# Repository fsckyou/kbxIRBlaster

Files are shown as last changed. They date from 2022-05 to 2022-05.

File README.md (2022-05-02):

# What the fork?
Yep, this project is a fork of the fantastic open hardware designed by Keith Burzinkski. Check out [the awesome design that this fork is based on](https://github.com/kbx81/kbxIRBlaster)! In many ways, this project is inferior to what he made, but intentionally inferior!

# Why the fork?
I used to buy Tuya IR blasters, pop them open and re-flash the firmware with ESPhome Like many IoT folks used to do. Then they stopped including wifi modules compatible with ESPhome. Well, left with no alternative, I guess I'll have to make them myself! A quick search found Keith's project which met most of my goals, but he designed it for high quality, maximum flexibility, and convenience of the user. My goal is primarily low cost, similarity to the old Tuya products, and bonus points if it can be assembled by JLC PCB.

# kbx and fsckyou IR Blaster

## What?

Just another ESP8266-based IR Blaster. It was designed with
 [ESPHome](https://esphome.io) in mind but should work fine with
 [Tasmota](https://tasmota.github.io/docs/) or any other app, really.

This design is round and should be pretty omnidirectional similar to the Tuya products you can buy on Amazon or Aliexpress.

I'll post images once I have them produced. As of now, this is only a design in progress.

## How?

I'll fill this part in later once the design is more final. ;)

 ## Legal stuff and License

The circuit schematics and PCB found here are licensed under the
 [Creative Commons Attribution-ShareAlike 4.0 International License](http://creativecommons.org/licenses/by-sa/4.0/).



_Happy building!_

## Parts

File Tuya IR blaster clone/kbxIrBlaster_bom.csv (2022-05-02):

Component | Quantity Per PCB | References | Value | MPN1 | MPN2 | Footprint | Population
1 | 3 | C6 C7 C8 | 100 nF | CC0805KRX7R7BB104 |  | C_0805_2012Metric
2 | 1 | C1 | 1 uF | C0805C105K4RACTU |  | C_0805_2012Metric
3 | 1 | C5 | 4.7 uF | C2012X5R1H475K125AB |  | C_0805_2012Metric
4 | 4 | C2 C3 C4 C9 | 10 uF | GRM21BC81C106ME15L |  | C_0805_2012Metric
5 | 2 | D1 D2 | 5V | LSM0805543V |  | LED_0805_2012Metric
6 | 8 | D10 D12 D14 D16 D18 D20 D22 D24 | CH1 | LTE-4206 |  | LED_D5.0mm
7 | 8 | D9 D11 D13 D15 D17 D19 D21 D23 | CH1 | APT2012F3C |  | LED_0805_2012Metric
8 | 5 | D5 D6 D7 D8 D29 | CH1 | APT2012EC |  | LED_0805_2012Metric
9 | 3 | D25 D26 D28 | MBR120 | MBR120VLSFT1G |  | D_SOD-123F
10 | 1 | D3 | STATUS | APT2012SECK |  | LED_0805_2012Metric
11 | 1 | D27 | TX | APT2012VBC/D |  | LED_0805_2012Metric
12 | 1 | D4 | USER | APT2012SYCK |  | LED_0805_2012Metric
13 | 1 | D30 | VBUS | APT2012ZGCK |  | LED_0805_2012Metric
14 | 1 | J3 | 5 TO 6 VDC | 163-179PH-EX |  | BarrelJack_Horizontal
15 | 1 | J2 | N/A | 105017-0001 |  | USB_Micro-B_Molex-105017-0001
16 | 5 | Q1 Q2 Q3 Q4 Q7 | 2N7002 | 2N7002-7-F |  | SOT-23
17 | 2 | Q5 Q6 | MMSS8050 | MMSS8050 |  | SOT-23
18 | 4 | R10 R12 R14 R16 | 27 | RC0805FR-0727RL |  | R_0805_2012Metric
19 | 4 | R9 R11 R13 R15 | 51 | RC0805FR-0751RL |  | R_0805_2012Metric
20 | 1 | R3 | 120 | RT0805FRE07120RL |  | R_0805_2012Metric
21 | 7 | R4 R5 R6 R7 R8 R20 R22 | 1K2 | RT0805FRE072K7L |  | R_0805_2012Metric
22 | 1 | R2 | 1K6 | RT0805FRE071K6L |  | R_0805_2012Metric
23 | 1 | R19 | 4K7 | RT0805FRE074K7L |  | R_0805_2012Metric
24 | 1 | R1 | 8K2 | RT0805FRE078K2L |  | R_0805_2012Metric
25 | 6 | R17 R18 R21 R23 R24 R25 | 10K | RC0805FR-0710KL |  | R_0805_2012Metric
26 | 2 | SW1 SW2 | RESET | PTS645VK582LFS |  | SW_Tactile_SPST_Angled_PTS645Vx58-2LFS
27 | 1 | U2 | AP2112K-3.3 | AP2112M-3.3TRG1 |  | SOT-23-5
28 | 1 | U1 | ESP32-WROOM-32D | ESP32-WROOM-32D |  | ESP32-WROOM-32
29 | 1 | U3 | FT232RL | FT232RL |  | SSOP-28_5.3x10.2mm_P0.65mm
30 | 1 | U4 | TSOP382xx | TSOP38238 |  | Vishay_MINICAST-3Pin
31 | 1 | U5 | TSOP382xx | TSOP38256 |  | Vishay_MINICAST-3Pin

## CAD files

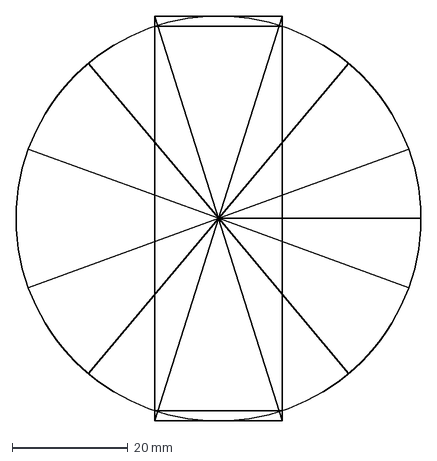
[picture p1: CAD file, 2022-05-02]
Tuya IR blaster clone/kbxIrBlasterDiscPCB.dxf
70.0 x 70.0 mm

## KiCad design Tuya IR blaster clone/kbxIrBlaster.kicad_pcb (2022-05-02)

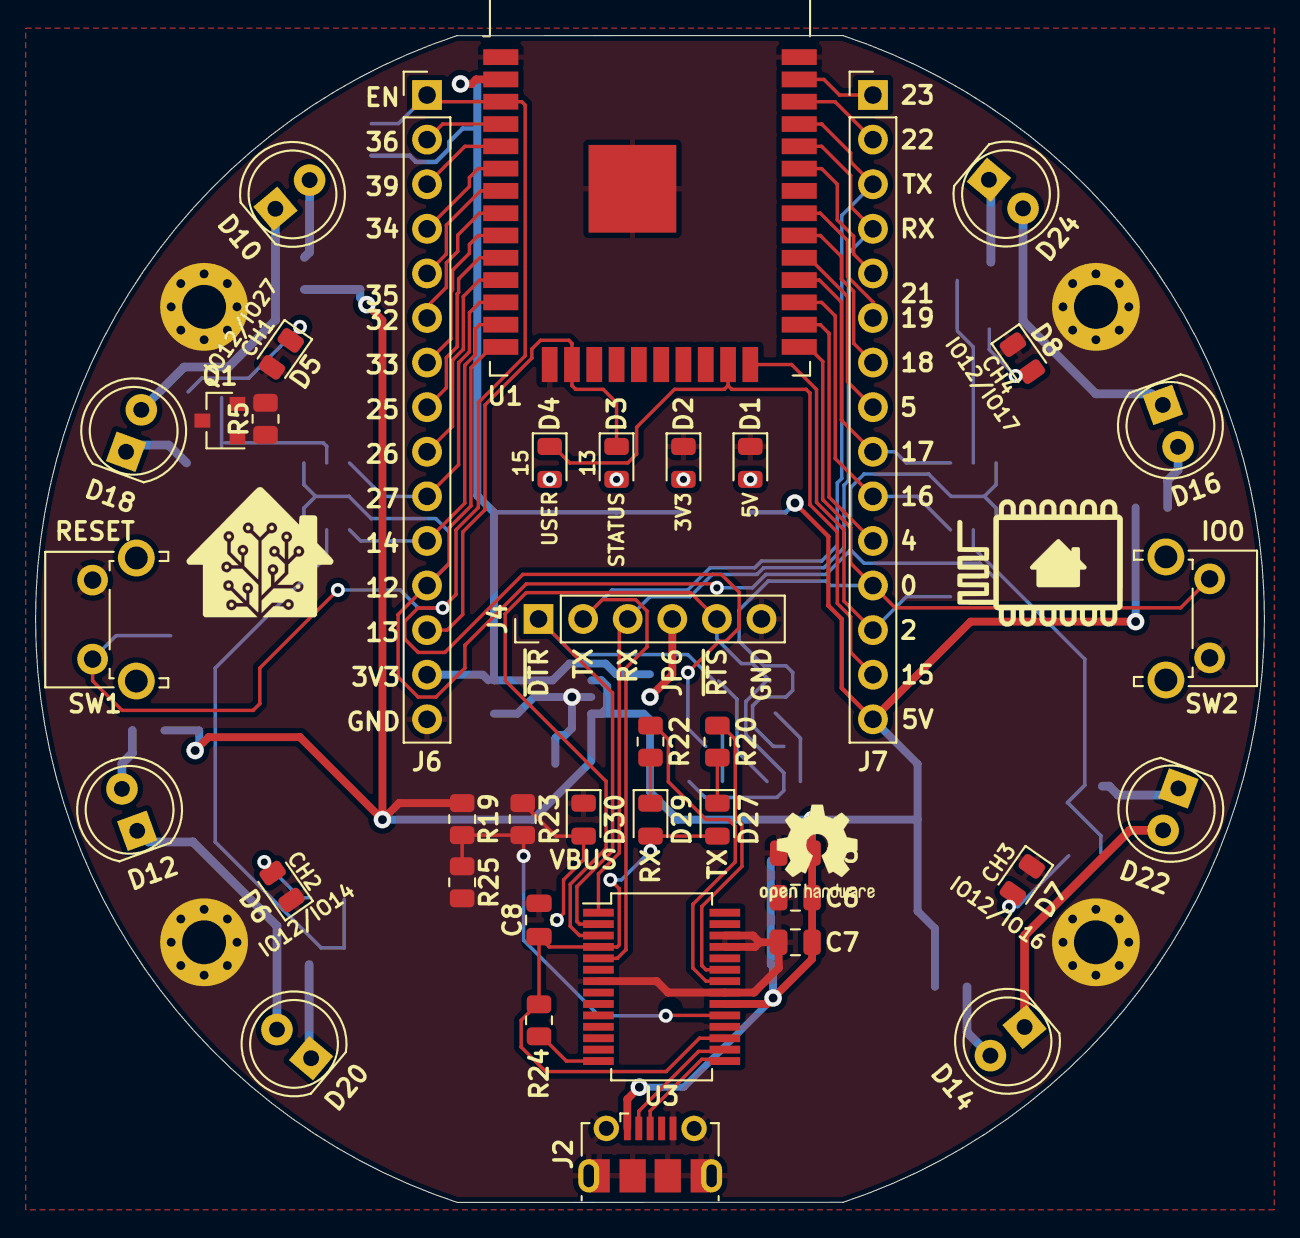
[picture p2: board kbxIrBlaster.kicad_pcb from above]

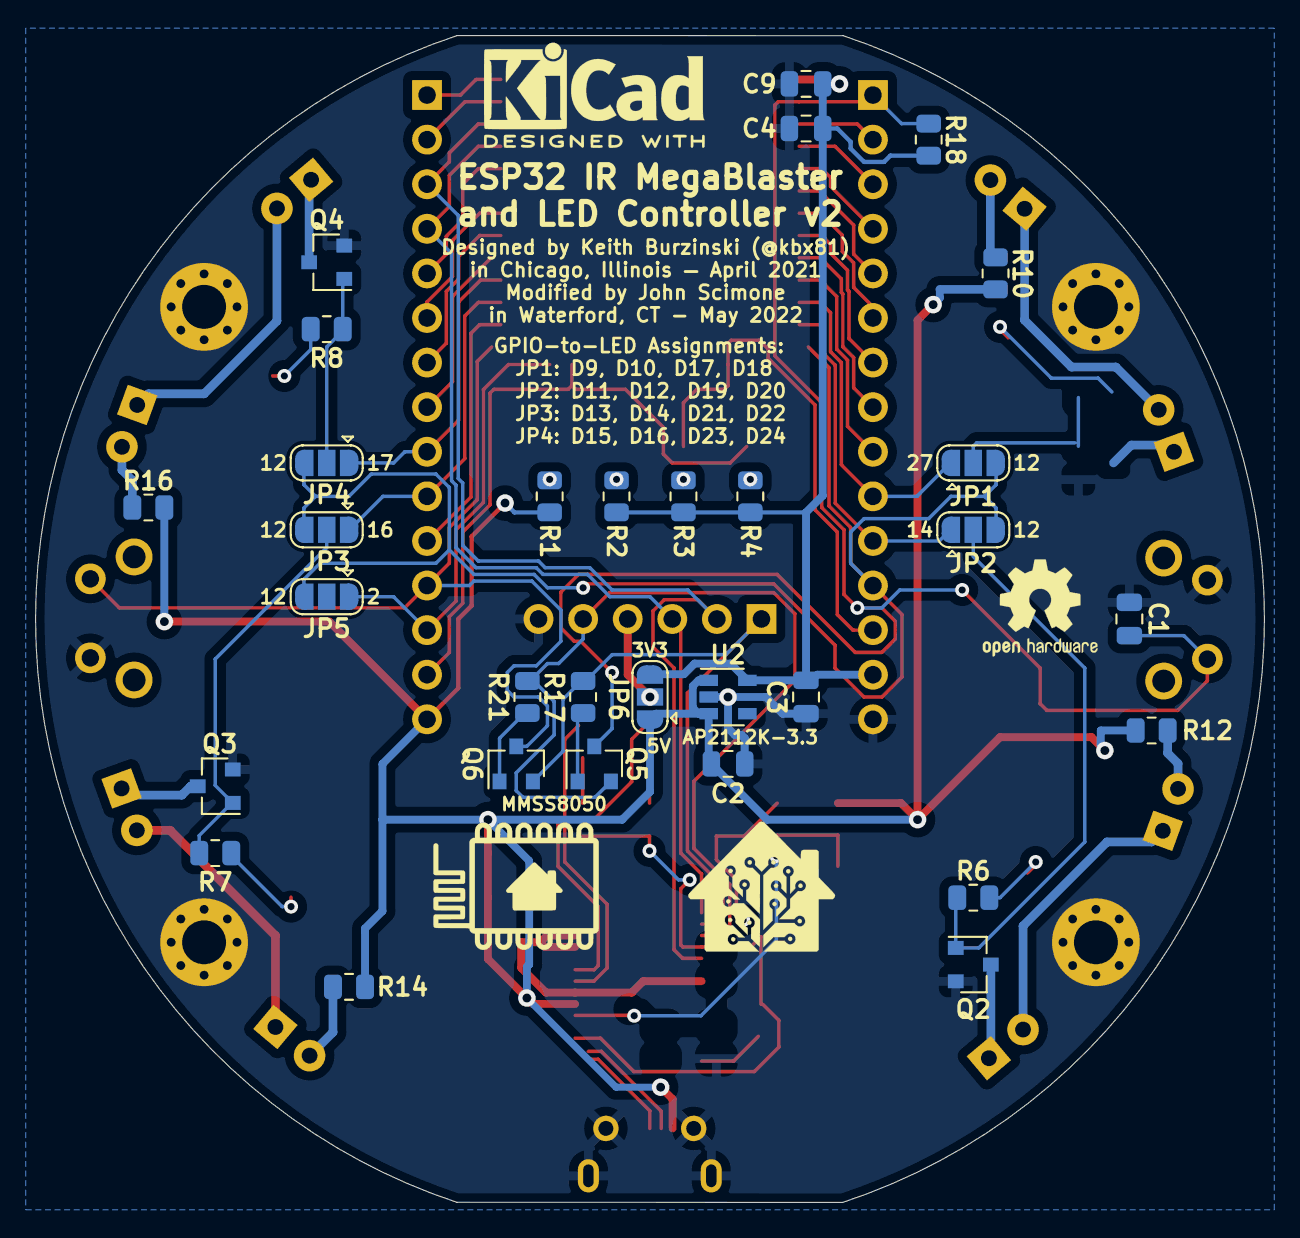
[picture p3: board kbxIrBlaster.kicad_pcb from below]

Board: 2 copper layers, 70.0 x 66.5 mm, 74 parts (31 on the bottom side), 69 nets.

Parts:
C1: 1 uF; C_0805_2012Metric
C2, C3, C4, C9: 10 uF; C_0805_2012Metric
C5: 4.7 uF; C_0805_2012Metric
C6, C7, C8: 100 nF; C_0805_2012Metric
D1: 5V; LED_0805_2012Metric
D2: 3V3; LED_0805_2012Metric
D3: STATUS; LED_0805_2012Metric
D4: USER; LED_0805_2012Metric
D5: CH1; LED_0805_2012Metric
D6: CH2; LED_0805_2012Metric
D7: CH3; LED_0805_2012Metric
D8: CH4; LED_0805_2012Metric
D10, D18: CH1; LED_D5.0mm
D12, D20: CH2; LED_D5.0mm
D14, D22: CH3; LED_D5.0mm
D16, D24: CH4; LED_D5.0mm
D27: TX; LED_0805_2012Metric
D29: RX; LED_0805_2012Metric
D30: VBUS; LED_0805_2012Metric
H1, H2, H3, H4: -; MountingHole_2.5mm_Pad_Via
J2: N/A; USB_Micro-B_Molex-105017-0001
J4: SERIAL; PinHeader_1x06_P2.54mm_Vertical
J6, J7: IO; PinHeader_1x15_P2.54mm_Vertical
JP1: IO12/IO27; SolderJumper-3_P1.3mm_Open_RoundedPad1.0x1.5mm
JP2: IO12/IO14; SolderJumper-3_P1.3mm_Open_RoundedPad1.0x1.5mm
JP3: IO12/IO16; SolderJumper-3_P1.3mm_Open_RoundedPad1.0x1.5mm
JP4: IO12/IO17; SolderJumper-3_P1.3mm_Open_RoundedPad1.0x1.5mm
JP5: IO12/IO2; SolderJumper-3_P1.3mm_Open_RoundedPad1.0x1.5mm
JP6: 5V/3V3; SolderJumper-3_P1.3mm_Open_RoundedPad1.0x1.5mm
Q1, Q2, Q3, Q4: 2N7002; SOT-23
Q5, Q6: MMSS8050; SOT-23
R1: 8K2; R_0805_2012Metric
R2: 1K6; R_0805_2012Metric
R3: 120; R_0805_2012Metric
R4, R20: 1K2; R_0805_2012Metric
R5, R6, R7, R8, R22: 2K7; R_0805_2012Metric
R10, R12, R14, R16: 27; R_0805_2012Metric
R17, R18, R21, R23, R24, R25: 10K; R_0805_2012Metric
R19: 4K7; R_0805_2012Metric
SW1: RESET; SW_Tactile_SPST_Angled_PTS645Vx58-2LFS
SW2: IO0; SW_Tactile_SPST_Angled_PTS645Vx58-2LFS
U1: ESP32-WROOM-32D; ESP32-WROOM-32
U2: AP2112K-3.3; SOT-23-5
U3: FT232RL; SSOP-28_5.3x10.2mm_P0.65mm

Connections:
+3V3: C3.2, C4.2, C9.2, J6.14, JP6.3 (B), R2.1, R3.1, R4.1, R18.1, U1.2 (VDD), U2.5 (VOUT)
+5V: C2.2, C5.1, C6.1, C7.1, J2.1 (VBUS), J7.15, JP6.1 (A), R1.1, R10.1, R12.1, R14.1, R16.1, R19.2, U2.1 (VIN), U2.3 (EN), U3.20 (VCC)
/ESP_EN: C1.1, J6.1, Q5.3 (C), R18.2, SW1.1, U1.3 (EN)
/ESP_RXD: J4.3, J7.4, U1.34 (RXD0/IO3), U3.1 (TXD)
/ESP_TXD: J4.2, J7.3, U1.35 (TXD0/IO1), U3.5 (RXD)
/FET1: D18.1 (K), Q1.3 (D)
/FET2: D20.1 (K), Q2.3 (D)
/FET3: D22.1 (K), Q3.3 (D)
/FET4: D24.1 (K), Q4.3 (D)
/GATE1: JP1.2 (C), Q1.1 (G), R5.1
/GATE2: JP2.2 (C), Q2.1 (G), R6.1
/GATE3: JP3.2 (C), Q3.1 (G), R7.1
/GATE4: JP4.2 (C), Q4.1 (G), R8.1
/GPI34: J6.4, U1.6 (IO34)
/GPI35: J6.5, U1.7 (IO35)
/GPI36: J6.2, U1.4 (SENSOR_VP)
/GPI39: J6.3, U1.5 (SENSOR_VN)
/GPIO0: J7.12, Q6.3 (C), SW2.1, U1.25 (IO0)
/GPIO2: J7.13, JP5.1 (A), U1.24 (IO2)
/GPIO4: J7.11, U1.26 (IO4)
/GPIO5: J7.8, U1.29 (IO5)
/GPIO12: J6.12, JP1.3 (B), JP2.3 (B), JP3.3 (B), JP4.3 (B), JP5.3 (B), U1.14 (IO12)
/GPIO13: D3.1 (K), J6.13, U1.16 (IO13)
/GPIO14: J6.11, JP2.1 (A), U1.13 (IO14)
/GPIO15: D4.1 (K), J7.14, U1.23 (IO15)
/GPIO16: J7.10, JP3.1 (A), U1.27 (IO16)
/GPIO17: J7.9, JP4.1 (A), U1.28 (IO17)
/GPIO18: J7.7, U1.30 (IO18)
/GPIO19: J7.6, U1.31 (IO19)
/GPIO21: J7.5, U1.33 (IO21)
/GPIO22: J7.2, U1.36 (IO22)
/GPIO23: J7.1, U1.37 (IO23)
/GPIO25: J6.8, U1.10 (IO25)
/GPIO26: J6.9, U1.11 (IO26)
/GPIO27: J6.10, JP1.1 (A), U1.12 (IO27)
/GPIO32: J6.6, U1.8 (IO32)
/GPIO33: J6.7, U1.9 (IO33)
/USB_D+: J2.3 (D+), U3.15 (USBD+)
/USB_D-: J2.2 (D-), U3.16 (USBD-)
/USB_~RESET: R19.1, R23.2, R25.2, U3.19 (~RESET)
/~DTR: J4.1, Q6.2 (E), R17.2, U3.2 (DTR)
/~RTS: J4.5, Q5.2 (E), R21.2, U3.3 (RTS)
GND: C1.2, C2.1, C3.1, C4.1, C5.2, C6.2, C7.2, C8.2, C9.1, D1.1 (K), D2.1 (K), D5.1 (K), D6.1 (K), D7.1 (K), D8.1 (K), D30.1 (K), H1.1, H2.1, H3.1, H4.1, J2.5 (GND), J2.6 (Shield), J4.6, J6.15, Q1.2 (S), Q2.2 (S), Q3.2 (S), Q4.2 (S), R25.1, SW1.2, SW2.2, U1.1 (GND), U1.15 (GND), U1.38 (GND), U1.39 (GND), U2.2 (GND), U3.7 (GND), U3.18 (GND), U3.21 (GND), U3.25 (AGND), U3.26 (TEST)
unnamed: C8.1, D27.2 (A), D29.2 (A), R24.1, U3.4 (VCCIO), U3.17 (3V3OUT)
unnamed: D1.2 (A), R1.2
unnamed: D2.2 (A), R2.2
unnamed: D3.2 (A), R3.2
unnamed: D4.2 (A), R4.2
unnamed: D5.2 (A), R5.2
unnamed: D10.1 (K), D18.2 (A)
unnamed: D10.2 (A), R10.2
unnamed: D12.1 (K), D20.2 (A)
unnamed: D12.2 (A), R12.2
unnamed: D14.1 (K), D22.2 (A)
unnamed: D14.2 (A), R14.2
unnamed: D16.1 (K), D24.2 (A)
unnamed: D16.2 (A), R16.2
unnamed: D27.1 (K), R20.1
unnamed: D29.1 (K), R22.1
unnamed: D30.2 (A), R23.1
unnamed: J4.4, JP6.2 (C)
unnamed: Q5.1 (B), R17.1
unnamed: Q6.1 (B), R21.1
unnamed: D6.2 (A), R6.2
unnamed: D7.2 (A), R7.2
unnamed: D8.2 (A), R8.2
unnamed: R20.2, U3.23 (CBUS0)
unnamed: R22.2, U3.22 (CBUS1)
unnamed: R24.2, U3.14 (CBUS3)

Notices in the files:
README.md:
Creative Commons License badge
